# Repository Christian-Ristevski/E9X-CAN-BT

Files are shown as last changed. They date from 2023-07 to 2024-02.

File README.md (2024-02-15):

# E9X-CAN-BT

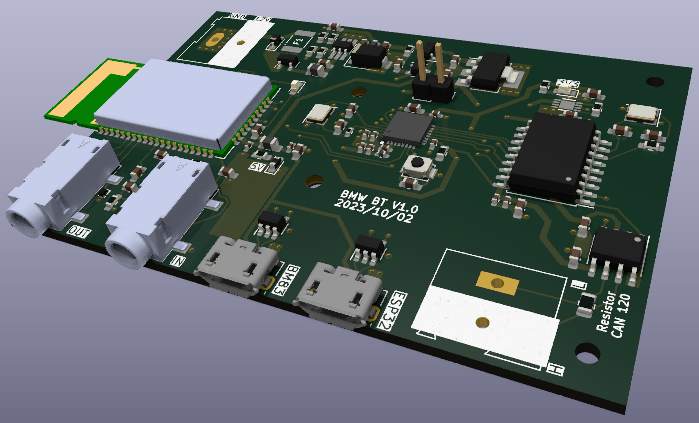
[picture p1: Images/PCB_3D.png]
Image of PCB 1.0 3D Rendition


## Problem Description
Many of the E9X series of BMW cars were manufactured without support for bluetooth music playback. To modernize these cars, many vendors have begun selling bluetooth-AUX modules of different kinds. The modules all come with the same problem, they aren't connected to the car's CAN network and therefore cannot utilize the built-in steering wheel radio controls. Forcing a driver to scramble around with their phone while driving is both inconvenient and unsafe and should prove easy to adress by designing a bluetooth module with CAN read functionality.

## Roadmap
- [x] Choose ICs (Programmable, CAN, Bluetooth)
- [x] Schematic (Communication)
- [x] Schematic (Power)
- [x] PCB layout and routing
- [x] PCB Manufacturing
- [x] PCB Assembly
- [x] Test power electronics
- [ ] Test program upload
- [ ] Functional testing (Whole PCB)
- [ ] Car installation
- [ ] System testing

## Requirements
* Bluetooth audio compatible with all smartphones (A2DP)
* Music controls though steering wheel (CAN bus)
* Invisible installation (Behind Radio)
* Runs from automotive 12 V line (Power electronics)

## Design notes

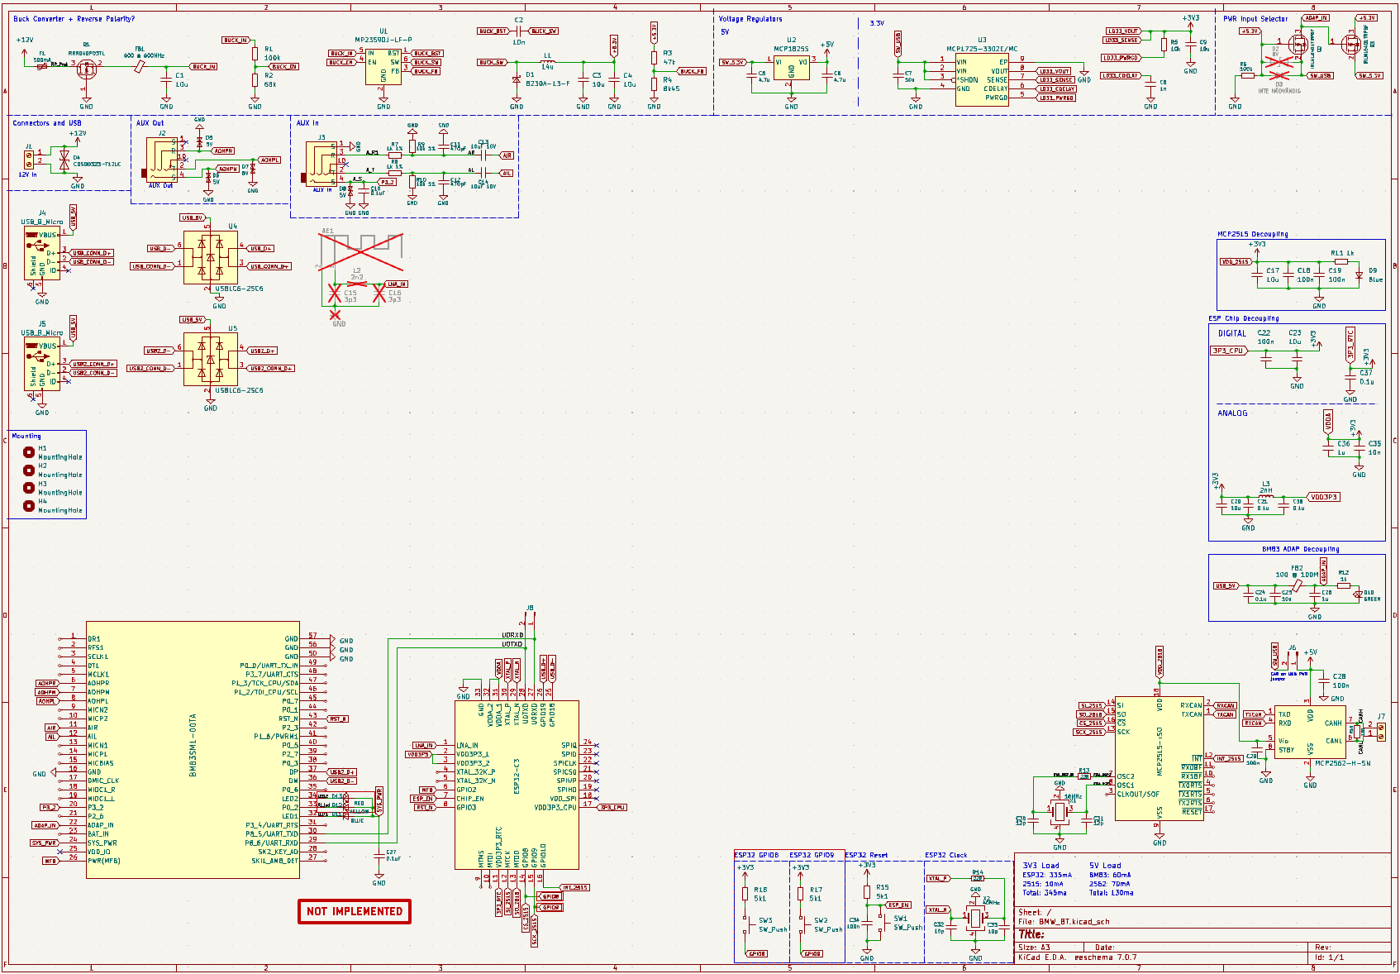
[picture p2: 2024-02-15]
Images/Schematic_Latest.png

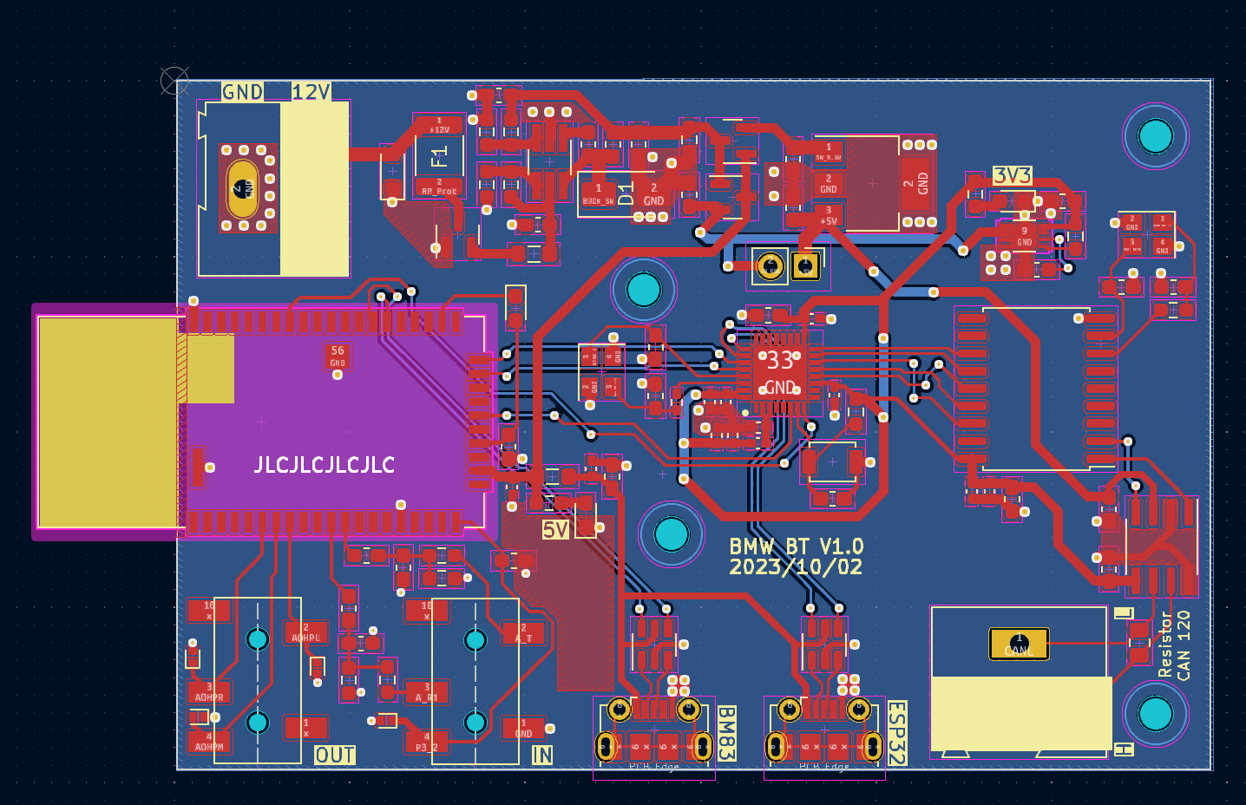
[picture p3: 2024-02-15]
Images/PCB_Top.png

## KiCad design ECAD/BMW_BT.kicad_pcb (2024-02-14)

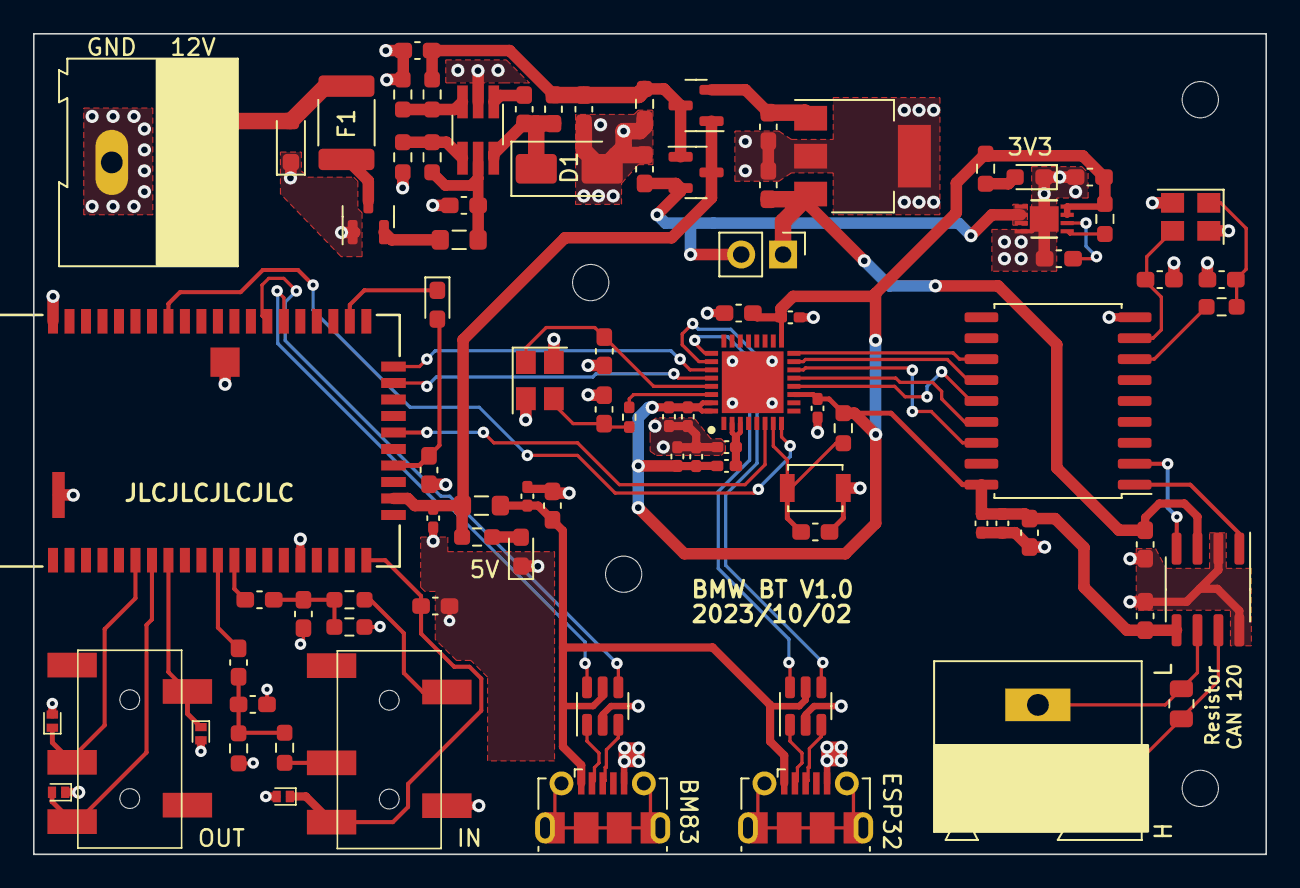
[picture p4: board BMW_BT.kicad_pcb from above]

Board: 2 copper layers, 74.8 x 49.8 mm, 92 parts (0 on the bottom side), 61 nets.

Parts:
C1, C3, C4, C7, C9, C17, C23, C25: 10u; C_0603_1608Metric_Pad1.08x0.95mm_HandSolder
C2: 10n; C_0603_1608Metric_Pad1.08x0.95mm_HandSolder
C5, C6: 4.7u; C_0603_1608Metric_Pad1.08x0.95mm_HandSolder
C8: 1n; C_0603_1608Metric_Pad1.08x0.95mm_HandSolder
C10, C27: 0.1uF; C_0603_1608Metric_Pad1.08x0.95mm_HandSolder
C11, C12: 470pF; C_0603_1608Metric_Pad1.08x0.95mm_HandSolder
C13, C14: 10uF 10V; C_0603_1608Metric_Pad1.08x0.95mm_HandSolder
C18, C19, C22: 100n; C_0402_1005Metric_Pad0.74x0.62mm_HandSolder
C20: 10u; C_0402_1005Metric_Pad0.74x0.62mm_HandSolder
C21, C24, C37, C38: 0.1u; C_0402_1005Metric_Pad0.74x0.62mm_HandSolder
C26, C36: 1u; C_0402_1005Metric_Pad0.74x0.62mm_HandSolder
C28, C29, C34: 100n; C_0603_1608Metric_Pad1.08x0.95mm_HandSolder
C30, C31: 12p; C_0603_1608Metric_Pad1.08x0.95mm_HandSolder
C32, C33: 10p; C_0603_1608Metric_Pad1.08x0.95mm_HandSolder
C35: 10n; C_0402_1005Metric_Pad0.74x0.62mm_HandSolder
D1: B230A-13-F; D_SMA
D4: CDSOD323-T12LC; D_SOD-323_HandSoldering
D5, D6, D7, D8: 5V; D_SOD-882
D9: Blue; LED_0603_1608Metric_Pad1.05x0.95mm_HandSolder
D10: GREEN; D_0603_1608Metric_Pad1.05x0.95mm_HandSolder
D11: BLUE; LED_0603_1608Metric_Pad1.05x0.95mm_HandSolder
F1: 500mA; Fuse_1812_4532Metric_Pad1.30x3.40mm_HandSolder
FB1: 600 @ 600MHz; L_0805_2012Metric_Pad1.05x1.20mm_HandSolder
FB2: 100 @ 100M; L_0805_2012Metric_Pad1.05x1.20mm_HandSolder
H1, H2, H3, H4: MountingHole; MountingHole_2.2mm_M2
IC1: ESP32-C3; QFN50P500X500X90-33N-D
J1, J7: Screw_Terminal_01x02; TerminalBlock_Altech_AK300-2_P5.00mm
J2, J3: SJ2-35863B1-SMT-TR
J4, J5: USB_B_Micro; USB_Micro-B_Molex-105017-0001
J6: Conn_01x02_Pin; PinHeader_1x02_P2.54mm_Vertical
L1: 14u; L_0603_1608Metric_Pad1.05x0.95mm_HandSolder
L3: 2nH; L_0402_1005Metric_Pad0.77x0.64mm_HandSolder
Q1: RRR040P03TL; SOT-23
Q2, Q3: IRLML6401TRPBF; SOT-23
R1, R6: 100k; R_0603_1608Metric_Pad0.98x0.95mm_HandSolder
R2: 68k; R_0603_1608Metric_Pad0.98x0.95mm_HandSolder
R3: 47k; R_0603_1608Metric_Pad0.98x0.95mm_HandSolder
R4: 8k45; R_0603_1608Metric_Pad0.98x0.95mm_HandSolder
R5: 10k; R_0603_1608Metric_Pad0.98x0.95mm_HandSolder
R7, R8: 1k 1%; R_0603_1608Metric_Pad0.98x0.95mm_HandSolder
R9, R10: 10k 1%; R_0603_1608Metric_Pad0.98x0.95mm_HandSolder
R11, R12: 1k; R_0603_1608Metric_Pad0.98x0.95mm_HandSolder
R13: 22R; R_0603_1608Metric_Pad0.98x0.95mm_HandSolder
R14: 22R; R_0402_1005Metric_Pad0.72x0.64mm_HandSolder
R15: 5k1; R_0603_1608Metric_Pad0.98x0.95mm_HandSolder
R16: 100k; R_0805_2012Metric
SW1: SW_Push; SW_SPST_B3U-1000P
U1: MP2359DJ-LF-P; TSOT-23-6_HandSoldering
U2: MCP1825S; SOT-223-3_TabPin2
U3: MCP1725-3302E/MC; DFN8_2x3MC_MCH
U4, U5: USBLC6-2SC6; SOT-23-6
U6: BM83SM1-00TA; BM83_MCH
U7: MCP2515-xSO; SOIC-18W_7.5x11.6mm_P1.27mm
U8: MCP2562-H-SN; SOIC-8_3.9x4.9mm_P1.27mm
X1: 16MHz; Crystal_SMD_3225-4Pin_3.2x2.5mm
X2: 40MHz; Crystal_SMD_3225-4Pin_3.2x2.5mm

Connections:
3P3_CPU: C9.1, C17.1, C18.1, C19.1, C20.1, C21.1, C22.1, C23.1, C29.1, C35.1, C36.1, C37.1, IC1.11 (VDD3P3_RTC), IC1.17 (VDD3P3_CPU), IC1.31 (VDDA_1), IC1.32 (VDDA_2), L3.1, R5.1, R11.1, R15.1, U3.7 (SENSE), U3.8 (VOUT), U7.18 (VDD), U8.5 (Vio)
+5.3V: C3.1, C4.1, L1.2, Q2.1 (G), Q3.3 (D), R3.1, R6.1
+5V: C6.1, C28.1, J6.1, U2.3 (VO), U8.3 (VDD)
+12V: D4.2 (A2), F1.1, J1.1
/AL: C12.1, C14.1, R8.2, R10.2
/AR: C11.2, C13.1, R7.2, R9.1
/A_R1: J3.3 (R), R7.1
/A_T: J3.2 (T), R8.1
/CANH: J7.2, R16.1, U8.7 (CANH)
/CANL: J7.1, R16.2, U8.6 (CANL)
/LED1: D11.1 (K), U6.32 (LED1)
/RP_Prot: F1.2, Q1.3 (D)
/UART_RXD: IC1.28 (U0TXD), U6.29 (P8_6/UART_RXD)
/UART_TXD: IC1.27 (U0RXD), U6.30 (P8_5/UART_TXD)
/XTAL_MCP1: C31.1, U7.8 (OSC1), X1.3
/XTAL_MCP2: R13.1, U7.7 (OSC2)
/XTAL_MCP_IN: C30.1, R13.2, X1.1
ADAP_IN: C26.1, FB2.1, Q2.3 (D), Q3.1 (G), R12.1, U6.22 (ADAP_IN)
AIL: C14.2, U6.12 (AIL)
AIR: C13.2, U6.11 (AIR)
AOHPL: D7.1 (A1), J2.2 (T), U6.8 (AOHPL)
AOHPM: D6.2 (A2), J2.4 (S), U6.7 (AOHPM)
AOHPR: D5.1 (A1), J2.3 (R), U6.6 (AOHPR)
BUCK_BST: C2.1, U1.1 (BST)
BUCK_EN: R1.2, R2.1, U1.4 (EN)
BUCK_FB: R3.2, R4.1, U1.3 (FB)
BUCK_IN: C1.1, FB1.2, R1.1, U1.5 (IN)
BUCK_SW: C2.2, D1.1 (K), L1.1, U1.6 (SW)
CS_2515: IC1.14 (GPIO8), U7.16 (~CS)
ESP_EN: C34.1, IC1.7 (CHIP_EN), R15.2, SW1.1
GND: C1.2, C3.2, C4.2, C5.2, C6.2, C7.2, C8.2, C9.2, C10.2, C11.1, C12.2, C17.2, C18.2, C19.2, C20.2, C21.2, C22.2, C23.2, C24.2, C25.2, C26.2, C27.2, C28.2, C29.2, C30.2, C31.2, C32.2, C33.2, C34.2, C35.2, C36.2, C37.2, C38.2, D1.2 (A), D4.1 (A1), D5.2 (A2), D6.1 (A1), D7.2 (A2), D8.2 (A2), D9.1 (K), D10.1 (K), IC1.33 (GND), J1.2, J3.1 (S), J4.5 (GND), J5.5 (GND), Q1.1 (G), R2.2, R4.2, R6.2, R9.2, R10.1, SW1.2, U1.2 (GND), U2.2 (GND), U3.4 (GND), U3.9 (EP), U4.2 (GND), U5.2 (GND), U6.16 (GND), U6.50 (GND), U6.56 (GND), U6.57 (GND), U7.9 (VSS), U8.2 (VSS), U8.8 (STBY), X1.2, X1.4, X2.2, X2.4
INT_2515: IC1.16 (GPIO10), U7.12 (~INT)
LD33_CDELAY: C8.1, U3.6 (CDELAY)
LD33_PWRGD: R5.2, U3.5 (PWRGD)
MFB: IC1.6 (GPIO2), U6.26 (PWR(MFB))
unnamed: C33.1, R14.2, X2.3
unnamed: D9.2 (A), R11.2
unnamed: D10.2 (A), R12.2
unnamed: FB1.1, Q1.2 (S)
P3_2: C10.1, D8.1 (A1), J3.4 (S), U6.20 (P3_2)
RST_N: IC1.8 (GPIO3), U6.43 (RST_N)
RXCAN: U7.2 (RXCAN), U8.4 (RXD)
SCK_2515: IC1.15 (GPIO9), U7.13 (SCK)
SI_2515: IC1.12 (MTCK), U7.14 (SI)
SO_2515: IC1.13 (MTDO), U7.15 (SO)
SW_5.3V: C5.1, Q3.2 (S), U2.1 (VI)
SW_USB: C7.1, J6.2, Q2.2 (S), U3.1 (VIN), U3.2 (VIN), U3.3 (*SHDN)
SYS_PWR: C27.1, D11.2 (A), U6.24 (SYS_PWR)
TXCAN: U7.1 (TXCAN), U8.1 (TXD)
USB2_CONN_D+: J5.3 (D+), U5.3 (I/O2)
USB2_CONN_D-: J5.2 (D-), U5.1 (I/O1)
USB2_D+: U5.4 (I/O2), U6.37 (DP)
USB2_D-: U5.6 (I/O1), U6.36 (DM)
USB_5V: C24.1, C25.1, FB2.2, J4.1 (VBUS), J5.1 (VBUS), U4.5 (VBUS), U5.5 (VBUS)
USB_CONN_D+: J4.3 (D+), U4.3 (I/O2)
USB_CONN_D-: J4.2 (D-), U4.1 (I/O1)
USB_D+: IC1.26 (GPIO19), U4.4 (I/O2)
USB_D-: IC1.25 (GPIO18), U4.6 (I/O1)
VDD3P3: C38.1, IC1.2 (VDD3P3_1), IC1.3 (VDD3P3_2), L3.2
XTAL_N: C32.1, IC1.29 (XTAL_N), X2.1
XTAL_P: IC1.30 (XTAL_P), R14.1

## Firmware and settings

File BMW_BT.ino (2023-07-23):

#include <SPI.h>

#include <mcp2515.h>

const bool DEBUG = true;

const int SPI_CS_PIN = 999;         // Define chip-select pin for MCP (CAN) SPI interface
const int INT_PIN = 999;

const uint32_t FILTER_MASK = 11111111111;   // Use filter to isolate singular specified ID
const uint32_t FILTER_ID = 0x1D6;           // Steering wheel buttons CAN-ID

const int musicControlParameters[3] = {0x07, 0x09, 0x0A};   // BM83 AVRCP music_control command parameters (PP, Next, Prev)

struct can_frame canMsg;
volatile bool interrupt = false;
MCP2515 mcp2515(SPI_CS_PIN);


// MCP interrupt service routine
void IRAM_ATTR mcpIRS() {
    interrupt = true;
}


// Send UART message to BM83
void canForward(uint8_t commandParameter) {
    if (DEBUG) {Serial.println("---- Assembling BM83 Packet ----");}
    uint8_t packet[6];    // Fixed packet length, only intended to send "Music_Control"
    packet[0] = 0xAA;     // Start word
    packet[1] = 0x00;     // MSB of packet length
    packet[2] = 0x02;     // LSB of packet length
    packet[3] = 0x04;     // Music Control OP-code
    packet[4] = commandParameter;
    
    // Calcualte checksum
    uint8_t CHKSUM = 1 + ~(packet[1] + packet[2] + packet[3] + packet[4]);    // Checksum is 2's complement of byte 1-4
    packet[5] = CHKSUM;

    if (DEBUG) {Serial.println("---- Sent parameter: %d", packet[4]);}
    Serial.write(packet, 6);
}


void setup() {
  Serial.begin(115200);
  while(DEBUG && !Serial);    // Awaits connection to computer with DEBUG set to true

  // Configure MCP2515 object
  mcp2515.reset();
  mcp2515.setBitrate(CAN_100KBPS, MCP_8MHZ);
  mcp2515.setListenOnlyMode();
  Serial.println("---- CAN Controller Initialized Successfully ----");

  // Enable MCP2515 filters
  mcp2515.setConfigMode();
  mcp2515.setFilterMask(MCP2515::MASK0, false, FILTER_MASK);
  mcp2515.setFilter(MCP2515::RXF0, false, FILTER_ID);
  mcp2515.setListenOnlyMode();
  Serial.println("---- CAN Filter Initialized Successfully ----");

  // Configure external interrupt pin
  pinMode(INT_PIN, INPUT);
  attachInterrupt(INT_PIN, mcpIRS, FALLING);
  Serial.println("---- CAN Interrupt attached Successfully ----");
}


void loop() {
    if (interrupt) {
        interrupt = false;

        uint8_t irq = mcp2515.getInterrupts();

        if (irq & MCP2515::CANINTF_RX0IF) {
            if (mcp2515.readMessage(MCP2515::RXB0, &canMsg) == MCP2515::ERROR_OK) {    // Reads RXB0 buffer, if OK, stores in "canMsg"
                
                for (int i = 0; i<canMsg.can_dlc; i++)  {  // print the data
                    Serial.print(canMsg.data[i],HEX);
                    Serial.print(" ");
                }

                uint16_t canWord = (canMsg.data[0] << 8) + canMsg.data[1];   // Adding together CAN data's MSB and LSB through 1 Byte bitshift

                switch (canWord) {
                    // case 0xC80C:
                    // case 0xC40C:
                    case 0xE00C:
                        canForward(musicControlParameters[1]);    // Next
                    case 0xD00C:
                        canForward(musicControlParameters[2]);    // Prev
                    case 0xC10C:
                        canForward(musicControlParameters[0]);    // Play/Pause toggle
                    // case 0xC00D:
                    // case 0xC01C:
                    // case 0xC04C:
                    default:
                        break;
                }
            }
        }
    }
}

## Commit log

2023-07-23 Update BMW_BT.ino
    comment unused switch cases
2024-02-14 Uploaded ECAD files
    [BMW_BT.kicad_pcb, BMW_BT.kicad_sch, BluetoothModule.kicad_sch]
